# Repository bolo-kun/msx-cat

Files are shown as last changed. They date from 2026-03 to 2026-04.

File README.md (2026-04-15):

PCB works for games up to 64kb (it's bits, so in bytes it's 8kB). Carts above 64kb aren't natively supported by MSX and need a mapper.

Fixed wrong hole placement, reduced PCB size to make is cheaper to produce.

Chips the original project used are hard to get and pricey but W29EE011 and AM29F010B work flawless for me, other 29F010 chips should work as well (first two letters stand for chip maker)

If you want to put it into a cartridge shell, you need to solder the EEPROM directly to the PCB as it won't fit into the case with a DIP socket.

For chips I mentioned you need to pad the rom file as shown below on linux bash or on windows using [GIT-Bash](https://gitforwindows.org/):

```bash
# 16kb game:
cat rom16k.bin rom16k.bin rom16k.bin rom16k.bin rom16k.bin rom16k.bin rom16k.bin rom16k.bin > game128.bin

# 32kb game: 
cat rom32k.bin rom32k.bin rom32k.bin rom32k.bin > game128.bin

# 64kb game:
cat rom64k.bin rom64k.bin > game128.bin
```





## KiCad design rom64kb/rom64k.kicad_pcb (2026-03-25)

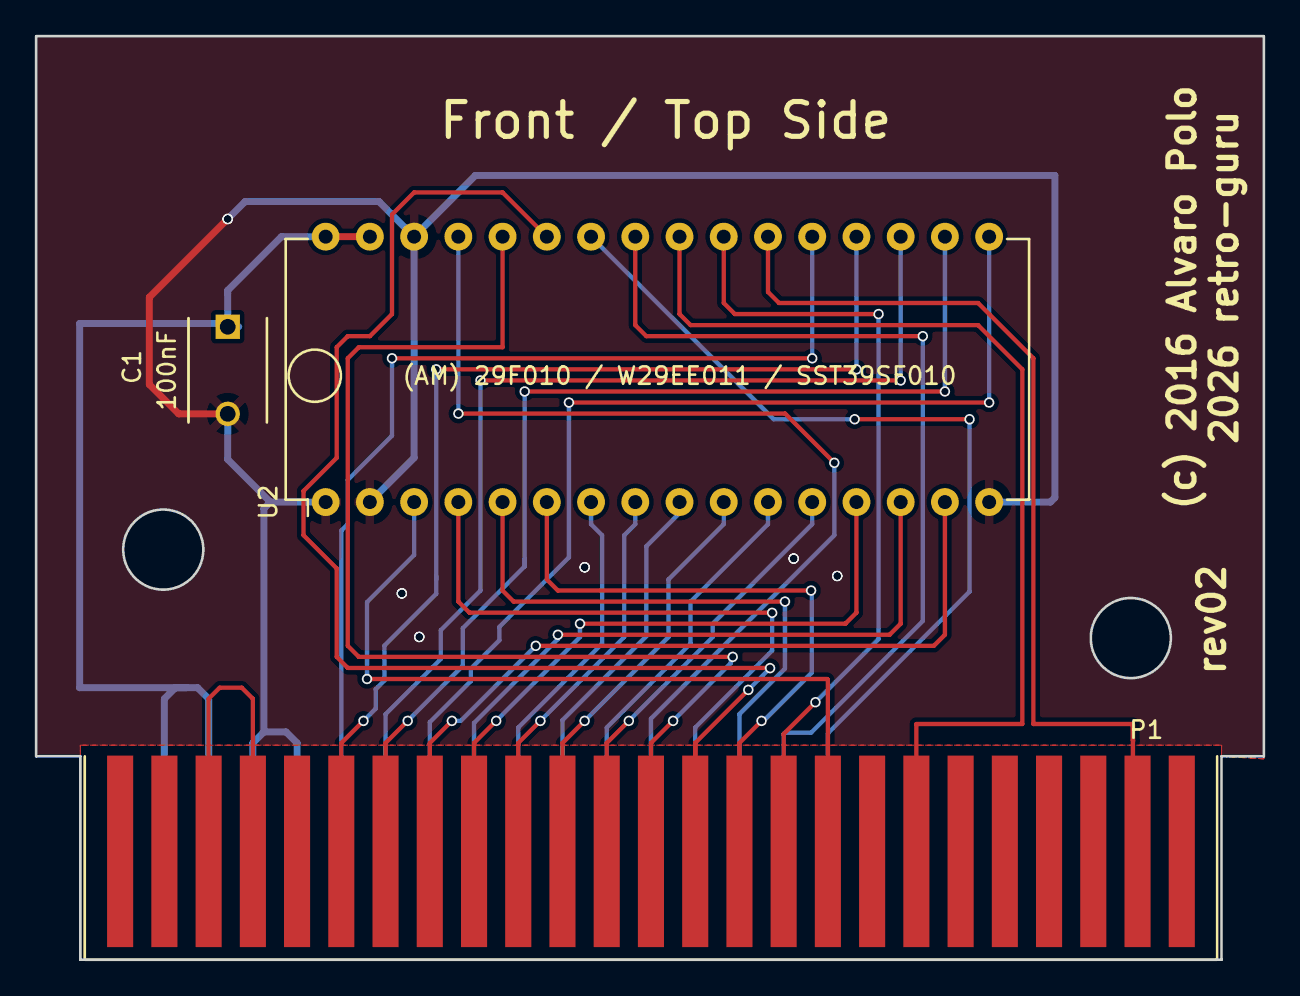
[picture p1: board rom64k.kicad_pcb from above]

Board: 2 copper layers, 70.5 x 53.0 mm, 3 parts (0 on the bottom side), 29 nets.

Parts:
C1: 100nF; C_Disc_D6_P5
P1: CONN_02X25; msx_cartridge
U2: (AM) 29F010 / W29EE011 / SST39SF010; DIP-32_W15.24mm

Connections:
/A0: P1.28, U2.12 (A0)
/A1: P1.27, U2.11 (A1)
/A2: P1.30, U2.10 (A2)
/A3: P1.29, U2.9 (A3)
/A4: P1.32, U2.8 (A4)
/A5: P1.31, U2.7 (A5)
/A6: P1.22, U2.6 (A6)
/A7: P1.21, U2.5 (A7)
/A8: P1.24, U2.27 (A8)
/A9: P1.17, U2.26 (A9)
/A10: P1.20, U2.23 (A10)
/A11: P1.19, U2.25 (A11)
/A12: P1.23, U2.4 (A12)
/A13: P1.26, U2.28 (A13)
/A14: P1.25, U2.29 (A14)
/A15: P1.18, U2.3 (A15)
/D0: P1.34, U2.13 (D0)
/D1: P1.33, U2.14 (D1)
/D2: P1.36, U2.15 (D2)
/D3: P1.35, U2.17 (D3)
/D4: P1.38, U2.18 (D4)
/D5: P1.37, U2.19 (D5)
/D6: P1.40, U2.20 (D6)
/D7: P1.39, U2.21 (D7)
GND: C1.2, P1.41, P1.43, U2.1 (NC), U2.2 (A16), U2.16 (GND), U2.30 (NC)
unnamed: P1.44, P1.46
VCC: C1.1, P1.45, P1.47, U2.31 (PGM), U2.32 (VCC)
~RD: P1.14, U2.24 (OE)
~SLTSL: P1.4, U2.22 (CE)

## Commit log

2026-03-25 Fixed hole placement, reduced PCB size for cost-cutting
    [rom64k.kicad_pcb]
2026-03-25 Update README with PCB design improvements
    Fixed wrong hole placement and reduced PCB size to lower production costs.
2026-03-26 Revise README with PCB details and ROM instructions
    Updated PCB specifications and usage instructions for MSX cartridges, including chip compatibility and ROM padding commands.
2026-04-04 Fix hole placement and reduce PCB size for cost

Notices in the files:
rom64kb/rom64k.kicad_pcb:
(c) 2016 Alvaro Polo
